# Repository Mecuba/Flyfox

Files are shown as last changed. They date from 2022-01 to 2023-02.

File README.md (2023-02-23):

# Flyfox | DIY Cablecam
Enlace al video de YouTube: https://www.youtube.com/watch?v=eEz6mBtRutU

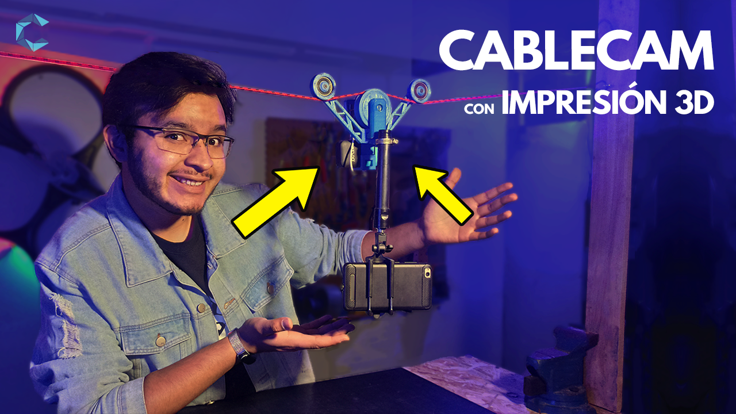
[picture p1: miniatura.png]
Flyfox Thumbnail (https://www.youtube.com/watch?v=eEz6mBtRutU)


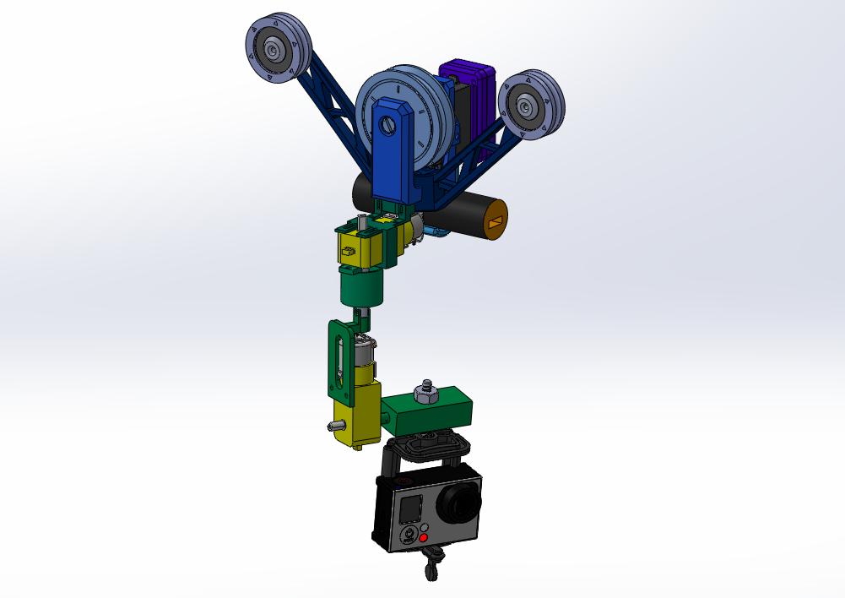
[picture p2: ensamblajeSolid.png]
Algoaca Thumbnail


Repo para guardar códigos y diseños mecánicos del Flyfox.

## Pendientes:
- Añadir algún día el estabilizador integrado como accesorio del Flyfox.
- Interfaz de control desde una app?

Si deseas más info sobre nuestro diseño de las piezas o hacer un diseño similar, escríbenos a: contacto.mecuba@gmail.com

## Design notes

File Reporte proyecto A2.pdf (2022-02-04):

### Benemérita Universidad Autónoma de Puebla Facultad de Ciencias de la Electrónica Avance II de proyecto Laboratorio Experimental de Sistemas Mecatrónicos

Nombre del proyecto:

### Desliza-inador

Fecha de entrega: 10 de noviembre de 2020 Fecha de envío: 10 de noviembre de 2020

Alumnos que la presentan:
Díaz Cisneros Sergio Fabrizzio | Jiménez Peña José Carlos
Flores Tecpoyotl Raymundo | Rojas López Daniel
González Montalvo Alejandro | Sánchez Saldaña Carlos Daniel

### I. Objetivo

Nuestro proyecto consiste en un dispositivo el cual es capaz de manipular los movimientos de una cámara, la cual estará sujetada al dispositivo a través de un sistema de sujeción, los movimientos se realizarán por medio de motores DC controlados por un potenciómetro. Nuestro dispositivo constará de dos movimientos principales, el primero será el desplazamiento de la cámara a través de una cuerda, el segundo consta de la rotación de la cámara para tener una vista de 360°. Como un adicional, se buscará lograr hacer una estabilización de la toma, aunque este punto no será tomado en cuenta para el mecanismo principal.

### II. Planos

Para empezar a plantear nuestro Desliza-inador, primero realizamos un prototipo en SolidWorks, mismo que será necesario en el análisis de este y la manipulación con Matlab y LabView.

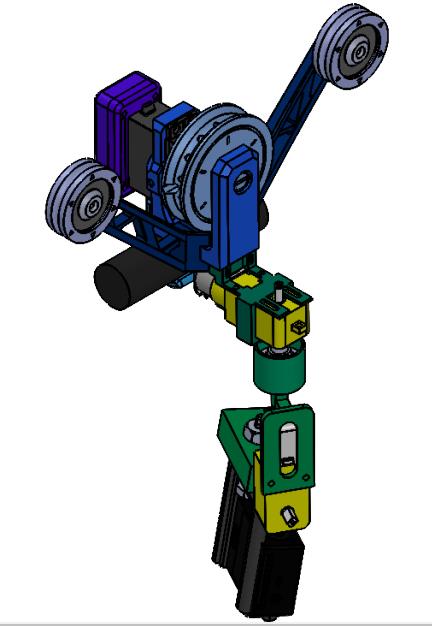
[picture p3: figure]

Figura 1. Desliza-inador en vista isométrica SolidWorks.

Planteamos 3 movimientos en nuestro sistema. El primero se trata de una traslación lineal sobre un eje, representado por ΔX en las figuras 2 y 3.
El segundo es un movimiento de giro ¨360¨ sobre un eje, el cuál resulta en el movimiento de giro de rotación sobre la cámara, siendo α en las figuras 2 y 3.
El tercero siendo un movimiento de giro acomodado en cadena bajo el movimiento 2, actuando como inclinación en la cámara, mostrado como γ en las figuras 2 y 3.

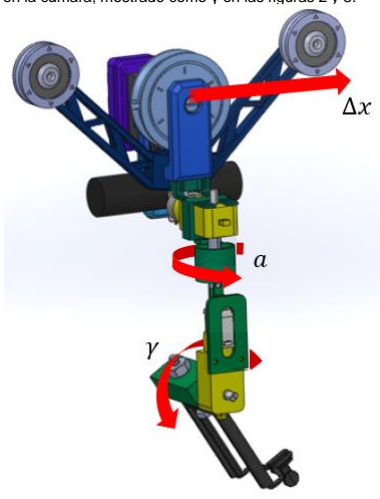
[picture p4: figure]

Figura 2. Desliza-inador en vista isométrica con ángulos de movimiento.

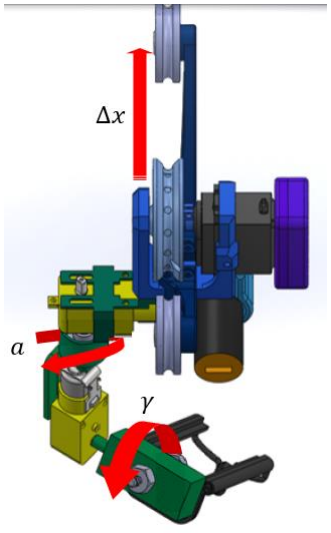
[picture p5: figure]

Figura 3. Desliza-inador con ángulos de giro en vista lateral. Podemos sintetizar los movimientos de nuestro sistema en el siguiente plano

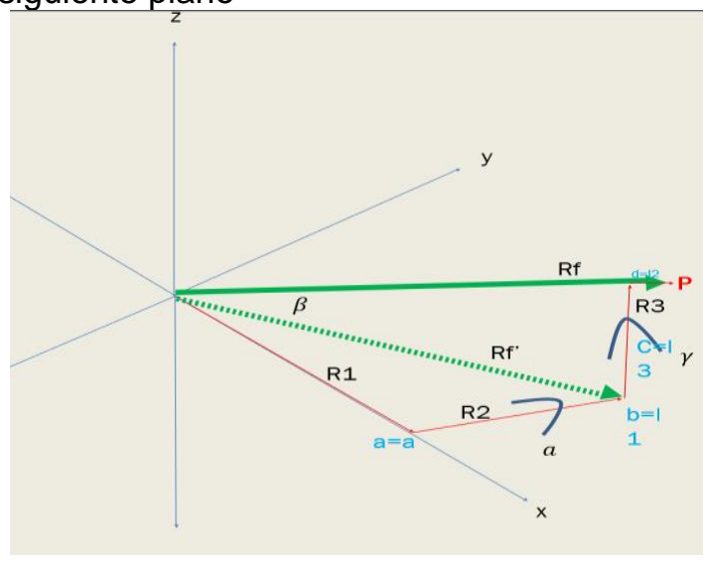
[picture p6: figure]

Figura 4. Plano 1

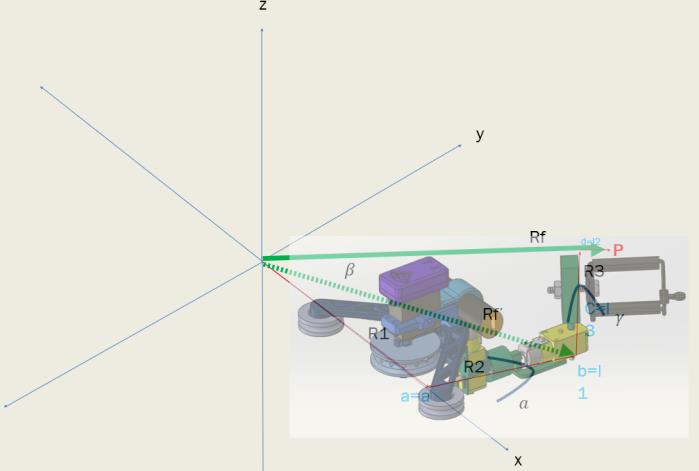
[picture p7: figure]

Figura 5. Plano 1 con representación directa.

Decidimos desplazar el Desliza-inador en el plano anterior reacomodando el sistema de referencia global para simplificar las ecuaciones y su adaptación a Matlab. El espacio (L1) que existe entre ΔX y α es una longitud invariable y resulta más fácil si ubicamos α en el eje X.
El deslizamiento principal ΔX sigue siendo sobre el eje X.
α ahora gira en paralelo al eje Y. L3 se puede mover en el plano XZ. Si el sistema está detenido como se muestra en la figura 6, L2 se puede mover en el plano XY, sin embargo, esto puede cambiar. Estos dos movimientos están relacionados estrechamente, el giro de α afecta directamente al punto P, el cual podría lograr movimientos circulares sobre el plano XY, esto cambiaria con el movimiento de γ rotando en el plano ZX.

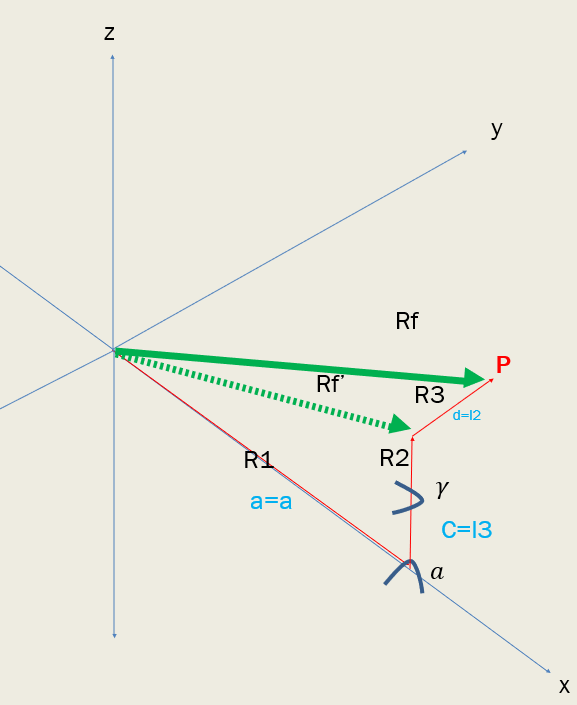
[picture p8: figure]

Figura 6. Plano 2

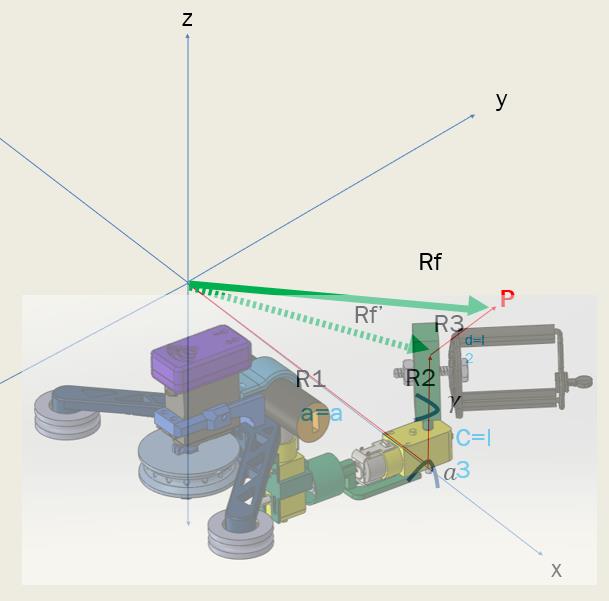
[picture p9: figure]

Figura 7. Plano 2 con representación directa.

Entonces para L2, al ser el segundo eslabón, no nos permite relacionar permanentemente solamente con un plano.
El movimiento que podemos imaginar se puede ver representado como la generación de anillos posibles dados por el giro de α. Formando una especie de dona que se puede deslizar en el eje X siendo este nuestro espacio muestral.

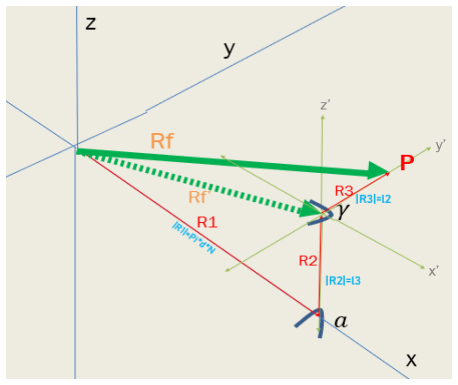
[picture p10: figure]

Figura 8. Plano 3

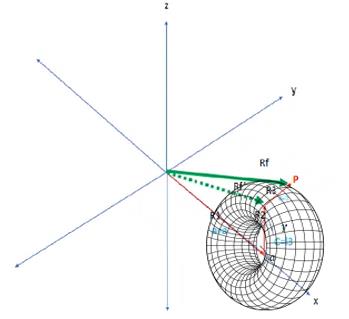
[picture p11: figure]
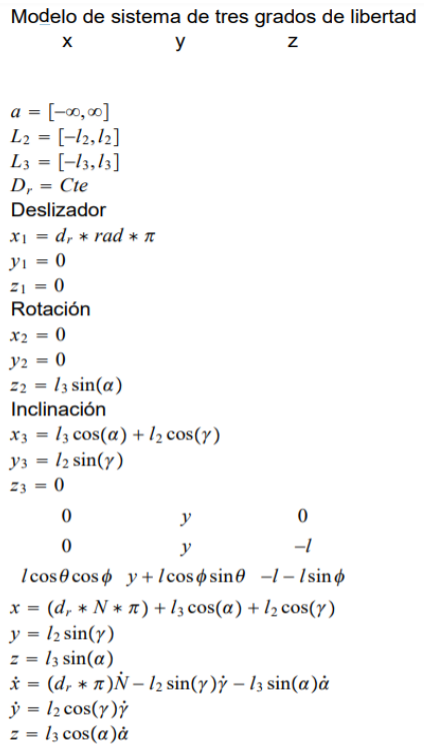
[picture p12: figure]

Figura 9. Plano 3 con representación de ¨dona¨

Si el movimiento de la dona se desliza en eje X, se generaría un prisma rectangular de posiciones posibles del punto P

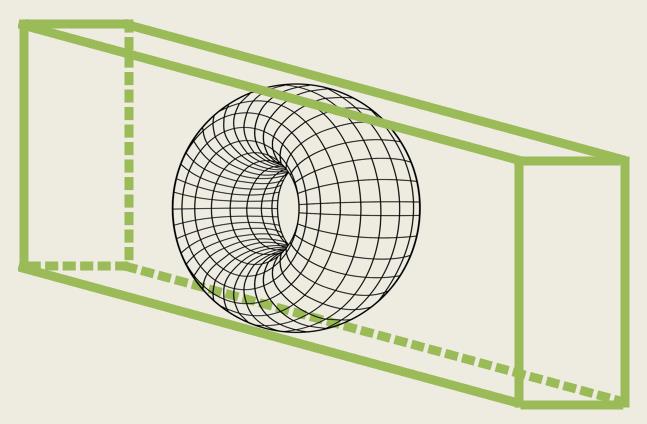
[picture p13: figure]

Figura 10. Espacio creado por el deslizamiento de la ¨dona¨

El deslizamiento podría ser considerado como infinito, generaría un rectángulo que se podría mover sobre x, dependiendo entonces de la cuerda sobre la cual este colocado el deslizador. Dominio de a: (-∞, ∞)î
El ancho de la caja seria 2 L2 comprendida de L2: (-L2, L2)ĵ
La altura L3 tendría dominio L3: (-L3, L3)k̂

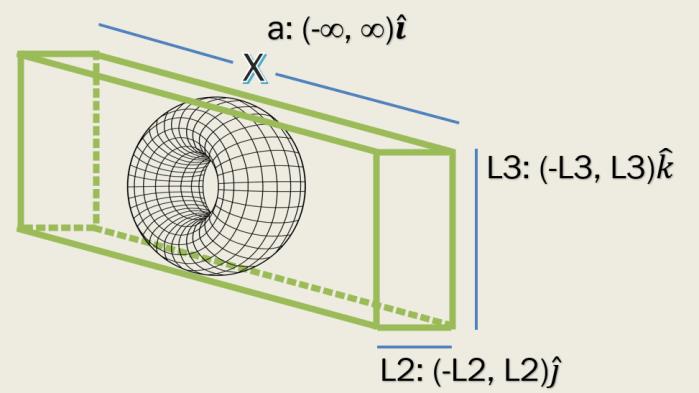
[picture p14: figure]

Figura 11. Parámetros del rectángulo generado.
III. | Matlab
Ya conociendo el sistema y | sus movimientos,
implementamos en Matlab para controlar el sistema. El código es el siguiente:

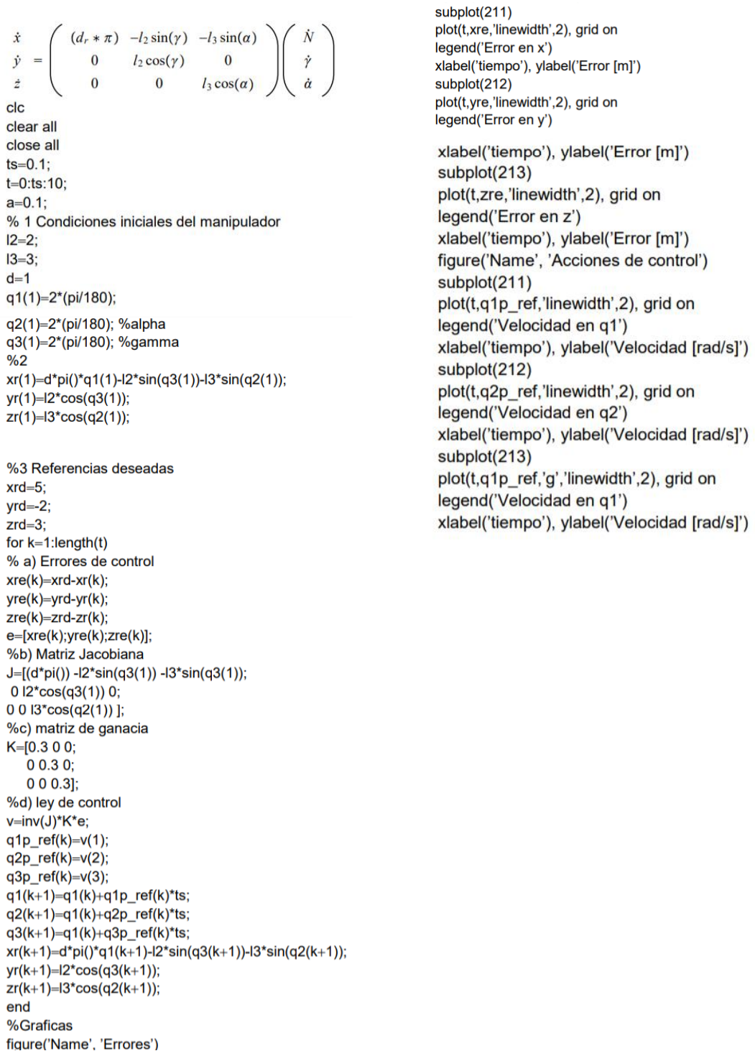
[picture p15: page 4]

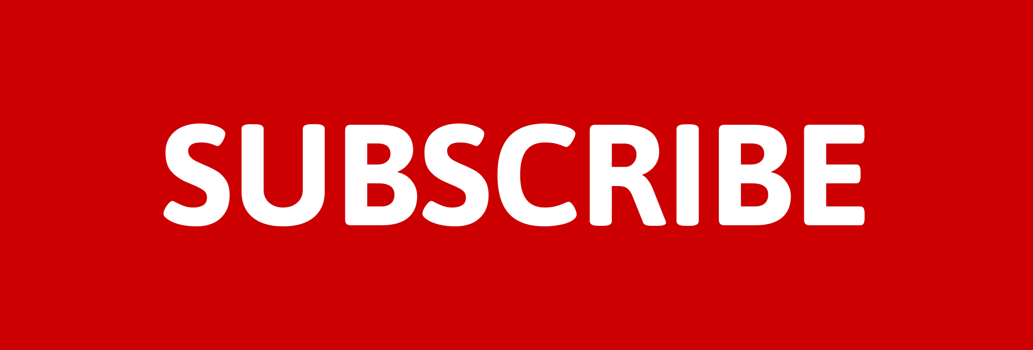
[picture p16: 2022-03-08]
CAD/STLs/youtube-subscribe-button/textures/subscribe.png

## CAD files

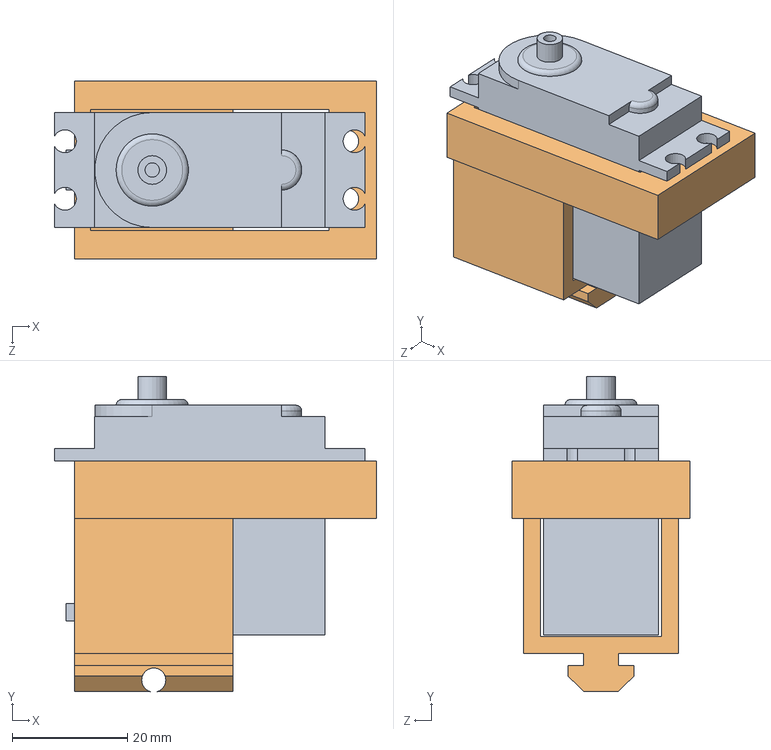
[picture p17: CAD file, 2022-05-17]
CAD/Flyfox - Ensamblaje Móvil con Servos/S20.000.v2 Pan.SLDASM
56.0 x 54.8 x 31.0 mm
servo strong junk 2.step
S20.002 Sujeta Servo Pan - PortaAccesorios

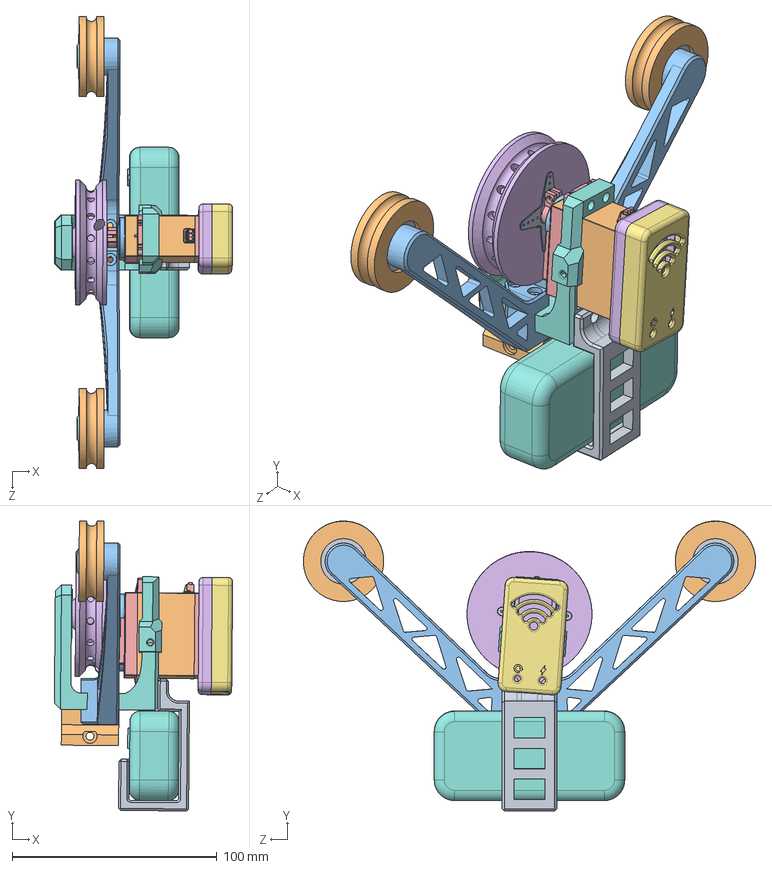
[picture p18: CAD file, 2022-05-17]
CAD/Flyfox - Ensamblaje Móvil con Servos/01 Flyfox Base/S10.000.v1.SLDASM
87.0 x 141.5 x 220.7 mm
Servo Futaba S3003.step
Servo Futaba S3003-0.step
Servo Futaba S3003-1.step
EMFutabaS3003_AxisFix
EMServoPolea
RodamientoServo^S10.000.v1
EMBastidorCentral x 2
EMRodamiento28x11.5x8 x 2
EMRodamientoSuit x 2
EMRightArm x 2
EMRodamientoRin x 2
MG995.step
Bottom.step
Top.step
EMPowerBank-Cuadrado
EMPortaPowerBank_Cuadrado
EMSlider-PortaAccesorios

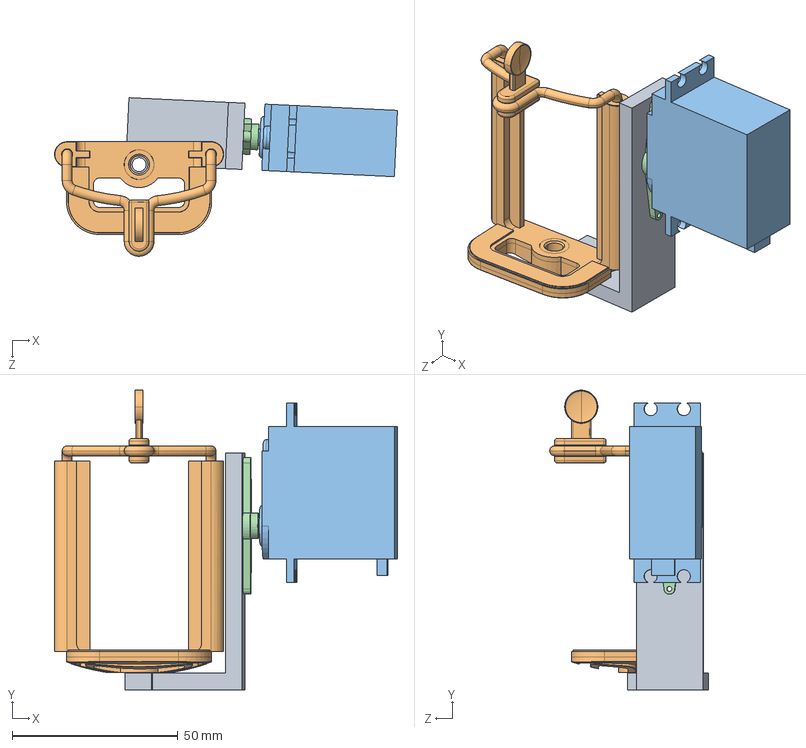
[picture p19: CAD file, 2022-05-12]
CAD/Flyfox - Ensamblaje Móvil con Servos/03 Tilt/S30.000.v1 Tilt.SLDASM
103.3 x 90.3 x 47.8 mm
S30.001 sujeta portatelefono
phone_holder
servo strong junk 2.step
servo strong junk 1.step

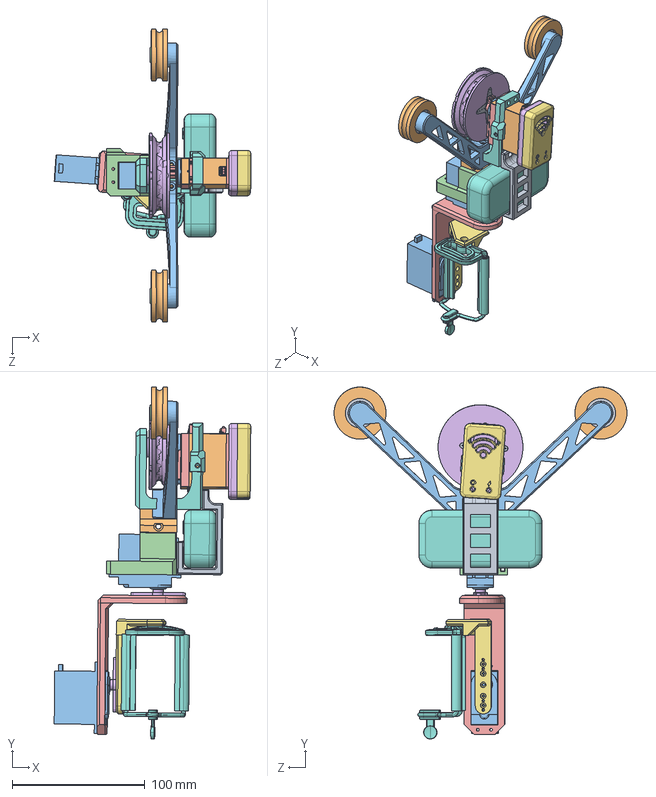
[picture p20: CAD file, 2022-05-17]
CAD/Flyfox - Ensamblaje Móvil con Servos/Ensamblaje_Movil_Flyfox_con_Torreta.SLDASM
148.2 x 265.2 x 220.7 mm
Servo Futaba S3003.step
Servo Futaba S3003-0.step
Servo Futaba S3003-1.step
EMFutabaS3003_AxisFix
RodamientoServo^S10.000.v1
EMBastidorCentral x 2
EMRodamiento28x11.5x8 x 2
EMRodamientoSuit x 2
EMRightArm x 2
EMRodamientoRin x 2
MG995.step
Bottom.step
Top.step
EMPowerBank-Cuadrado
EMPortaPowerBank_Cuadrado
EMSlider-PortaAccesorios
servo strong junk 2.step x 2
S20.002 Sujeta Servo Pan - PortaAccesorios
S20.001 Cople Pan-Tilt
servo mg995 horn 2 sides.step x 2
S30.001 sujeta portatelefono
phone_holder
EMServoPolea

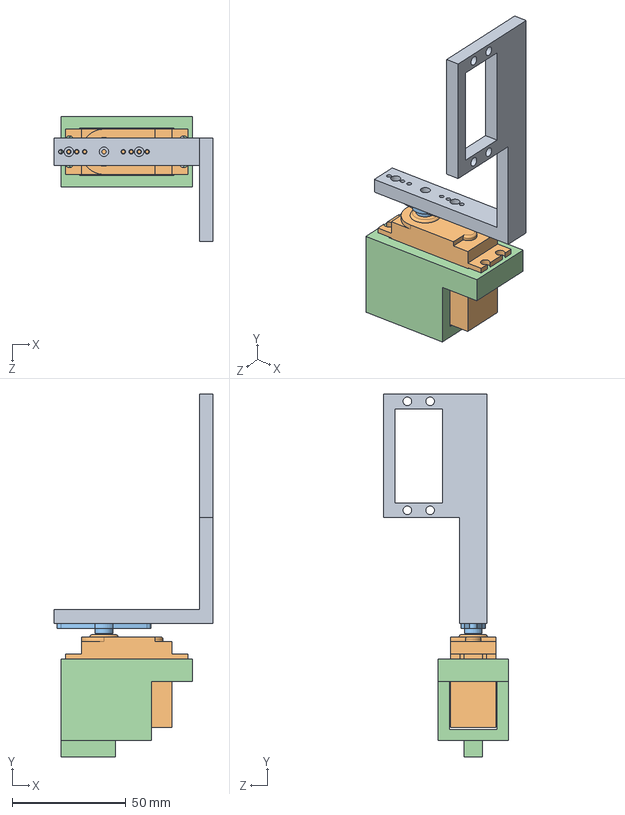
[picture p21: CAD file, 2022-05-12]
CAD/Flyfox - Ensamblaje Móvil con Servos/02 Pan/Ensamblaje2.SLDASM
70.0 x 159.9 x 55.0 mm
S20.001 Cople Pan-Tilt
servo strong junk 2.step
servo strong junk 1.step
S20.002 Sujeta Servo Pan - PortaAccesorios

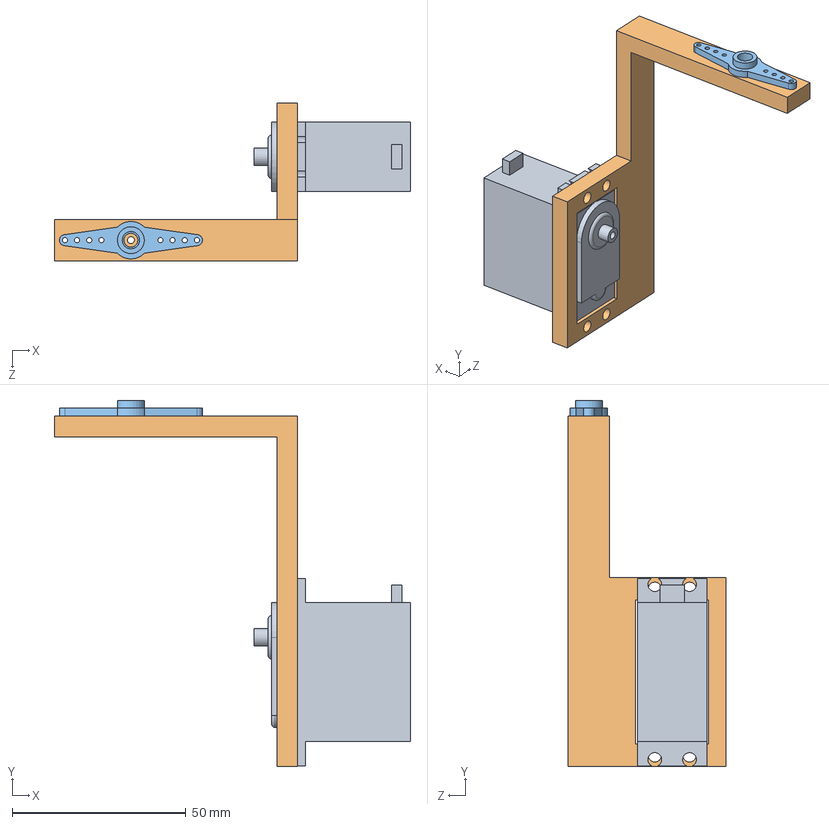
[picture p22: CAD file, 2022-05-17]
CAD/Flyfox - Ensamblaje Móvil con Servos/S30.000.v2 Tilt.SLDASM
102.5 x 105.5 x 45.5 mm
servo strong junk 2.step
S20.001 Cople Pan-Tilt
servo mg995 horn 2 sides.step

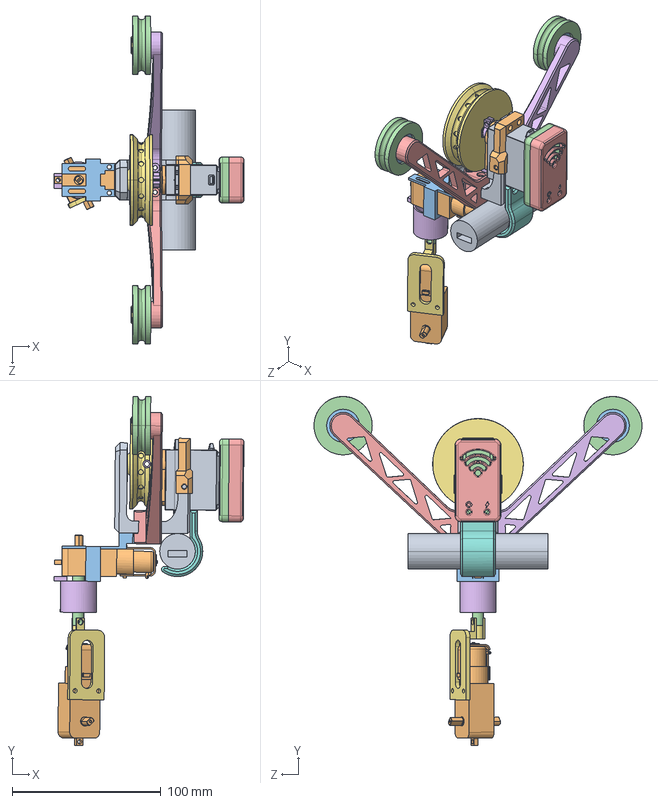
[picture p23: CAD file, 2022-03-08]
CAD/Servo Cable Cam (CUBA).SLDASM
127.8 x 234.9 x 220.7 mm
Servo Futaba S3003.step.STEP
Servo Futaba S3003-0.step.STEP
Servo Futaba S3003-1.step.STEP
Bottom.step.STEP
Top.step.STEP
FutabaS3003_AxisFix.STEP
ServoPolea.STEP
Pieza1^Servo Cable Cam.STEP
BastidorCentral_TopCut.STEP
Rodamiento28x11.5x8.STEP x 2
RodamientoSuit.STEP x 2
RightArm.STEP
RightArm_LeftMirror.STEP
RodamientoRin.STEP x 2
PortaPowerBank_Duracell.STEP
PowerBank-Dummy.STEP
Hobby_GearMotor x 2
Pieza2
Union Motor 1 y 2^Servo Cable Cam (Motor reductor)
Pieza7^Servo Cable Cam (Motor reductor)
Pieza8^Servo Cable Cam (Motor reductor)
Soporte Motor 2

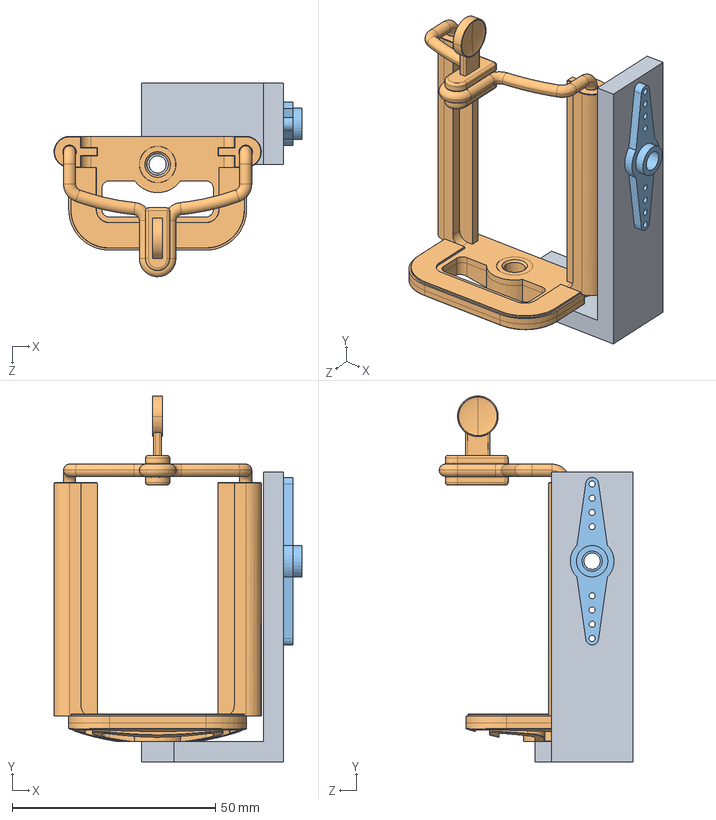
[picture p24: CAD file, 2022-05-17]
CAD/Flyfox - Ensamblaje Móvil con Servos/S40.000.v2 CAMERA END.SLDASM
61.0 x 90.0 x 47.6 mm
S30.001 sujeta portatelefono
phone_holder
servo mg995 horn 2 sides.step

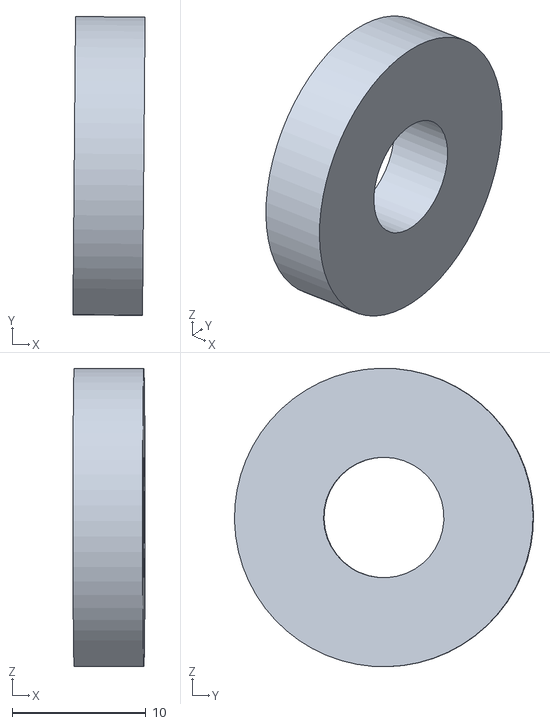
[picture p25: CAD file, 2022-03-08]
CAD/STLs/flyfox para gravity sketch/flyfox - RodamientoServo^Desliza-inador (Ensamblaje Completo).STL
5.39 x 22.3 x 22.3

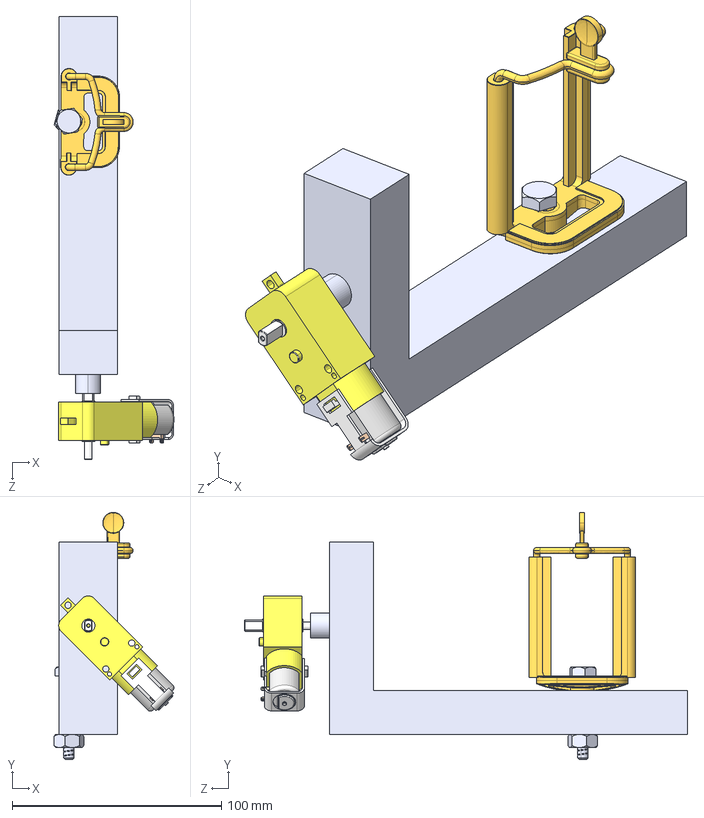
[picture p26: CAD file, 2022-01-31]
CAD/Ensamblaje Fabrizz.STEP
57.3 x 118.1 x 211.6 mm
Hobby_GearMotor
phone_holder
Tornillo
Tuerca
Sujeta Pinza

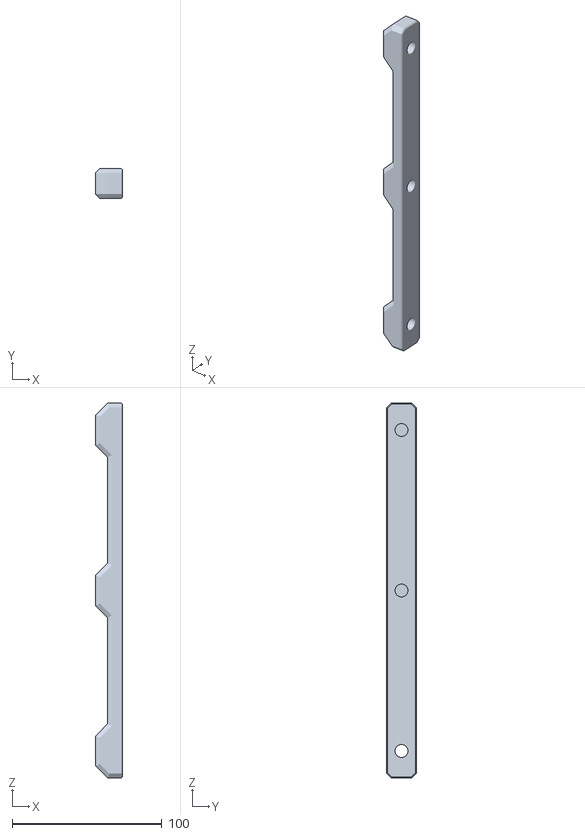
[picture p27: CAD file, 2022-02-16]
CAD/Accesorios/Carrete-Brazo para manviela.STL
18.0 x 20.0 x 250.0

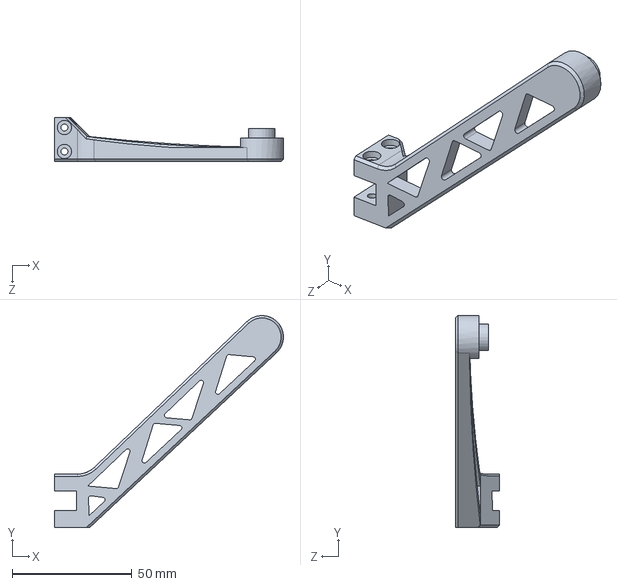
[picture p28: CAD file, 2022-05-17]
CAD/Flyfox - Ensamblaje Móvil con Servos/01 Flyfox Base/EMRightArm.SLDPRT
95.6 x 88.5 x 18.5 mm

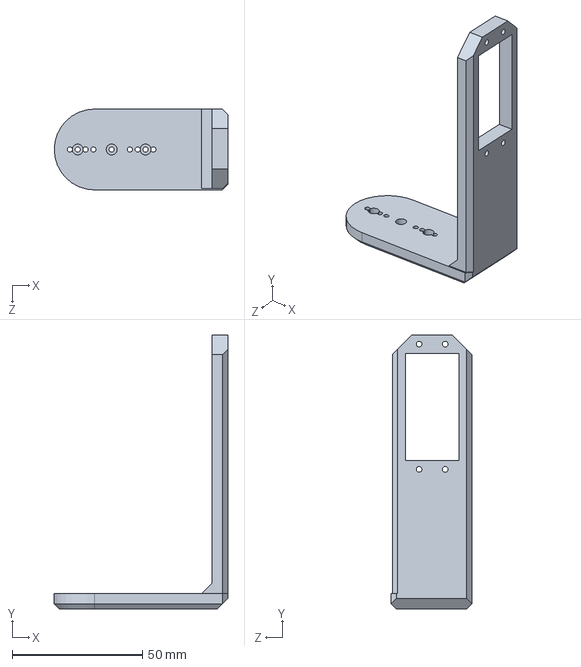
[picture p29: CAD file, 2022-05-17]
CAD/Flyfox - Ensamblaje Móvil con Servos/02 Pan/S20.001 Cople Pan-Tilt.SLDPRT
66.5 x 105.0 x 31.0 mm

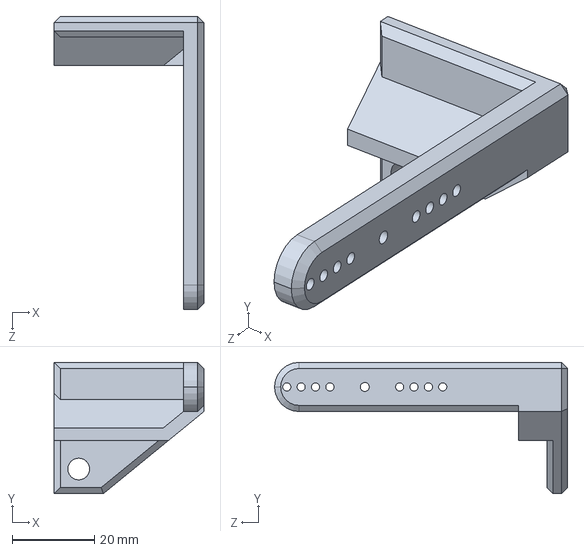
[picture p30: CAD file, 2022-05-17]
CAD/Flyfox - Ensamblaje Móvil con Servos/03 Tilt/S30.001 sujeta portatelefono.SLDPRT
36.5 x 32.0 x 71.4 mm

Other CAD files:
CAD/Flyfox - Ensamblaje Móvil con Servos/STEP Files/NodeMCU_Case_V2.step.STEP.sldasm
CAD/Servo Futaba S3003 v6.step.STEP.sldasm
CAD/Servo Cable Cam.STEP.sldasm
CAD/Flyfox - Ensamblaje Móvil con Servos/STEP Files/MG995_Gear2.STEP
CAD/Accesorios/Carrete-Brazo con manviela.SLDPRT
CAD/Accesorios/Carrete-Brazo para eje.STL
CAD/Accesorios/Finales de línea.SLDPRT
CAD/Accesorios/Finales de línea.STL
CAD/BastidorCentral.SLDPRT
CAD/BastidorCentral_RestCut.STEP.sldprt
CAD/BastidorCentral_TopCut.STEP.sldprt
CAD/Bottom.step.STEP.sldprt
CAD/Desliza-inador (Flyfox).SLDDRW
CAD/Flyfox - Ensamblaje Móvil con Servos/01 Flyfox Base/EMBastidorCentral.SLDPRT
CAD/Flyfox - Ensamblaje Móvil con Servos/01 Flyfox Base/EMFutabaS3003_AxisFix.SLDPRT
CAD/Flyfox - Ensamblaje Móvil con Servos/01 Flyfox Base/EMPortaPowerBank_Cuadrado.SLDPRT
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

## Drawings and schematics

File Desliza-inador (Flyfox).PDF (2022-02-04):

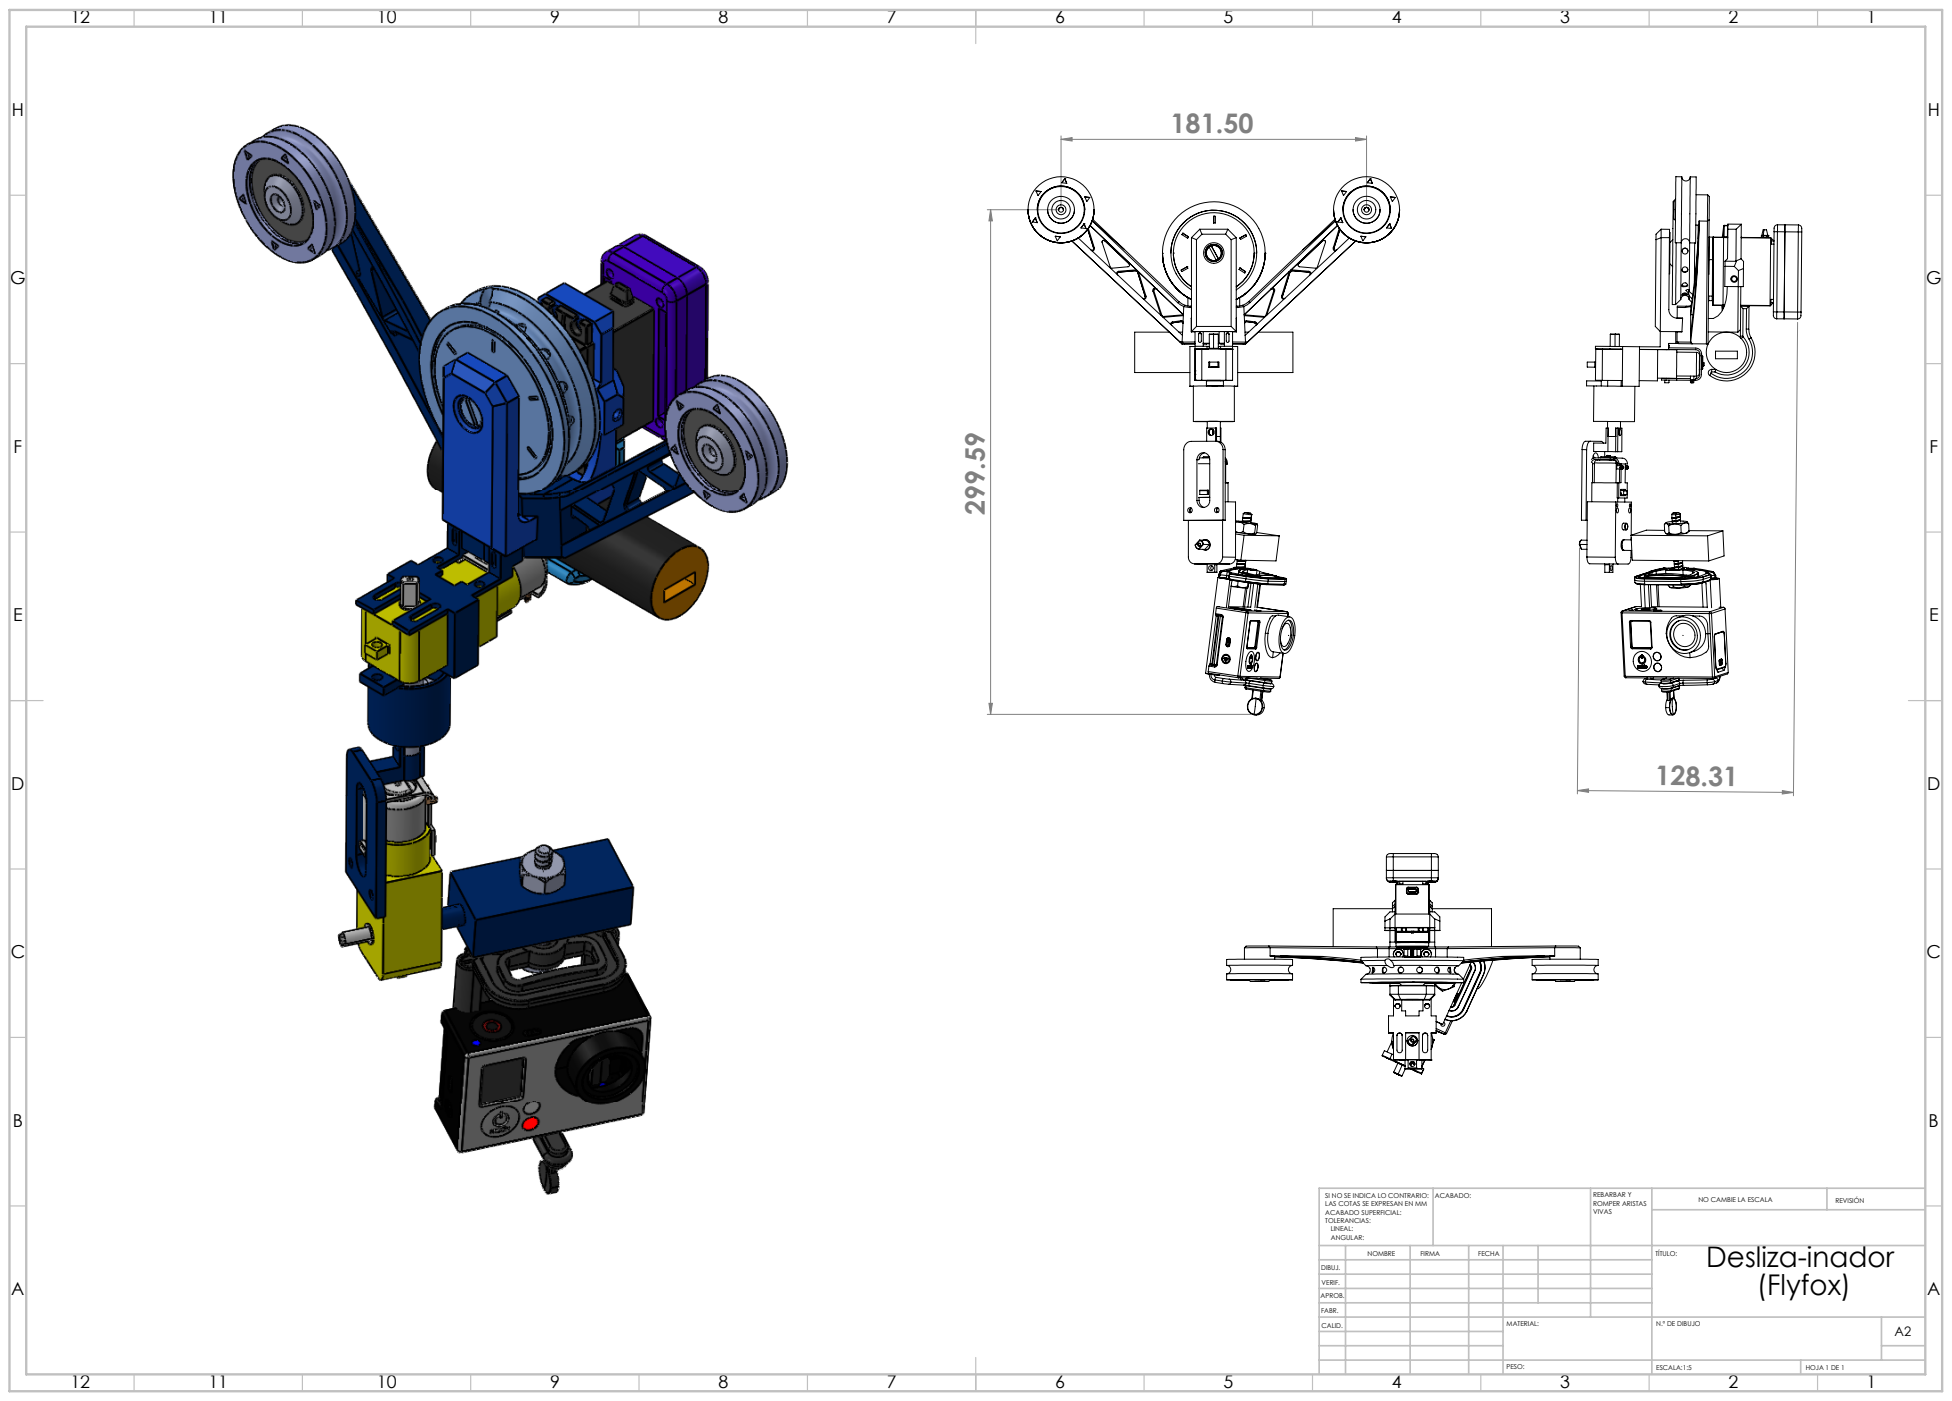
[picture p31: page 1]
ESCALA:1:5; HOJA 1 DE 1

SI NO SE INDICA LO CONTRARIO: LAS COTAS SE EXPRESAN EN MM ACABADO SUPERFICIAL: TOLERANCIAS: LINEAL: ANGULAR: | ACABADO: | REBARBAR Y ROMPER ARISTAS VIVAS | NO CAMBIE LA ESCALA | REVISIÓN

NOMBRE | FIRMA | FECHA | | | | Desliza-inador TÍTULO: (Flyfox)

DIBUJ.
VERIF.
APROB.
FABR.
CALID. | | | | MATERIAL: | N.º DE DIBUJO | A2

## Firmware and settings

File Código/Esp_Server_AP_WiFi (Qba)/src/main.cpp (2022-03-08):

#include <Arduino.h>
#include <ESP8266WebServer.h>
#include <ESP8266WiFi.h>
#include <WiFiClient.h>
#include <WebSocketsServer.h>
#include <Servo.h>
#include <string>

///Pagina html index.html/// 
#include <index.h>
#include <submit.h>
#include <error.h> //Aun no esta xd 

//Led de prueba: 
#define D4 2

//Declaramos el servo
Servo FlyServo; //Nombre del servo
#define servoPin D3 // El servo en el pin D3

//Parametros del bot
bool play = false;  
int range = 0; //Valor del slider: de 0 a 100* )99)
int sliderNum = 162;

//Parametros de red: 
String ip ;
IPAddress ipStatic(192,168,100,82);
IPAddress ipGateway(192,168,0,1);
IPAddress subnet(255,255,255,0); 
const char* ssid = "Flyfox-AP"; //Nombre del punto de acceso.
char* password;
char* nombre; 

//Contadores: 
int i = 0; 

//Iniciamos el sevidor en el puerto 80: 
ESP8266WebServer server(80);
WebSocketsServer webSockets = WebSocketsServer(81); 

/// Funciones: ////
bool toggle_button(String payload){
  //Cambia el valor del estado: 
  if (payload == "play")
        {
          return true;
        }else{
          return false;
        }
}
bool connected_to_wifi(char* name, char* pass){
  //Devuelve true si se pudo conectar: 

  Serial.printf("nombre: %s",name); 
  WiFi.config(ipStatic, ipGateway, subnet);
  WiFi.begin(name, pass); 
  Serial.print("\n\r ....");
  int time_finish = 0; 
  unsigned long int actual_time = millis();
  unsigned long int prev_time = millis();
  while ((WiFi.status() != WL_CONNECTED) && (time_finish != 1)){ 
    actual_time = millis();
    delay(200);
    Serial.println("No connected");
    if(actual_time - prev_time > 15000){
      prev_time = actual_time;
      time_finish = 1;
      Serial.println("Acabo el tiempo"); 
      return false;
    } 
  }return true;
}
void AP_mode(){
  //Crea un AP: 
  WiFi.softAP(ssid); 
  IPAddress miIP = WiFi.softAPIP(); //IP por default: 192.168.4.1  
  ip = miIP.toString();
  Serial.println("IP del APoint"); 
  Serial.println(miIP);
  Serial.println(WiFi.localIP()); 
}

//Manejo de peticiones http:  
void control_root(){
  //Interfaz de control:
   server.send(200,"text/html", html);
}
void handle_root(){
  String ip_AP = "192.168.4.1"; 
  if(ip == ip_AP){
    server.send(200, "text/html", submit_html);  
    Serial.println("Submit");
  }else{ 
    server.send(200,"text/html", html);
    Serial.println("Control root"); 
  }
}
void error_root(){
  server.send(200, "text/html", error);
}

//Manejo de las peticiones de websockets: 
void webSocketEvent(uint8_t num, WStype_t type, uint8_t *payload, size_t welength)
{
  String payloadString = (char *)payload;
  
  if(type == WStype_TEXT) 
  {
  // Que tipo de conexion es: 
  switch(type) {

    // Client has disconnected
    case WStype_DISCONNECTED:
      Serial.printf("[%u] Disconnected!\n", num);
      break;

    // New client has connected
    case WStype_CONNECTED:
      {
        IPAddress ip = webSockets.remoteIP(num);
        Serial.printf("[%u] Connection from ", num);
        Serial.println(ip.toString());
      }
      break;

    // Echo text message back to client
    case WStype_TEXT:
    { 
      Serial.printf("[%u] Text: %s\n", num, payload);
      char str1[30]; //Usado para dividir cadena de entrada del websocket. 
      for (int i = 0; i < payloadString.length(); i++)
      {
        str1[i] = {payloadString[i]};
      }  
      char* payloadString_first_position = strtok(str1, ",");
      char* payloadString_second_position = strtok(NULL, "");

      String payloadStringfirst = (char *)payloadString_first_position; 
      String payloadStringsecond = (char *)payloadString_second_position;       
      Serial.printf("payloadString_first_position: %s \n", payloadString_first_position); 
      
      //Verifica si son valores del slider: //ACÁ EDITAR PARA SERVO----------------------------------
      if(payloadStringfirst == "range"){
        range = payloadStringsecond.toInt();
        Serial.printf("Range: %i \n", range); 
        sliderNum = map(range, 0, 99, 144, 180);
        Serial.printf("sliderNum: %i \n", sliderNum); 

      //Si es play o stop: 
      }else if (payloadString == "play" || payloadString == "stop"){
        play = toggle_button(payloadString);
        Serial.println(play); 
        if(play)
        {
          
          //FlyServo.attach(servoPin);
          //delay(1000);
          FlyServo.write(sliderNum); //Rotate the servo
          Serial.println(sliderNum);
        }
        else
        {
          FlyServo.write(162); //Rotate the servo
          Serial.println(162);
          //FlyServo.detach();
        }

      //Si son credenciales de internet: 
      }else{
        char str[30]; //Usado para dividir cadena de entrada del websocket. 
        for (int i = 0; i < payloadString.length(); i++)
        {
          str[i] = {payloadString[i]};
        }  

        nombre = strtok(str, ","); 
        password = strtok(NULL, ""); 

        //Intenta conectarse a la red: 
        Serial.printf("nombre: %s, contraseña: %s",nombre, password); 
        WiFi.config(ipStatic, ipGateway, subnet);
        WiFi.begin(nombre, password); 
        Serial.print("\n\r ....");
        int time_finish = 0; 
        unsigned long int actual_time = millis();
        unsigned long int prev_time = millis();
        while ((WiFi.status() != WL_CONNECTED) && (time_finish != 1)){ 
        actual_time = millis();
        delay(200);
        Serial.println("No connected");
        if(actual_time - prev_time > 13000){
          prev_time = actual_time;
          time_finish = 1;
          Serial.println("Acabo el tiempo"); 
          } 
        }
        //No se pudo conectar: 
        if(WiFi.status() != WL_CONNECTED){
          Serial.println("No se pudo conectar"); 
          WiFi.disconnect(); 
        }
        //Se conecto: 
        else{
          Serial.println("Wifi conectada en la ip 192.168.100.82");  
          ip = "192.168.100.82"; 
          digitalWrite(D4,HIGH); 
        }
      }
    }
      break;

    // For everything else: do nothing
    case WStype_BIN:
    case WStype_ERROR:
    case WStype_FRAGMENT_TEXT_START:
    case WStype_FRAGMENT_BIN_START:
    case WStype_FRAGMENT:
    case WStype_FRAGMENT_FIN:
    default:
      break;
  }
  }
}


void setup() { //----------------------------------------------------------------------SETUP-------------------------------------------
  Serial.begin(9600);
  delay(500);
  Serial.println("Encendiendo Flyfox...");
  FlyServo.attach(servoPin);
  delay(100);
  FlyServo.write(162);
  int pos;

  for (pos = 0; pos <= 180; pos += 1) { // goes from 0 degrees to 180 degrees
    // in steps of 1 degree
    FlyServo.write(pos);              // tell servo to go to position in variable 'pos'
    Serial.println(pos);
    delay(200);                       // waits 15 ms for the servo to reach the position
  }
  for (pos = 180; pos >= 0; pos -= 1) { // goes from 180 degrees to 0 degrees
    FlyServo.write(pos);              // tell servo to go to position in variable 'pos'
    Serial.println(pos);
    delay(200);                       // waits 15 ms for the servo to reach the position
  }

  WiFiMode(WIFI_AP_STA);
  //Intenta conectarse a una red pasada (AUN NO ESTA)
  if(nombre != NULL){
    if(connected_to_wifi(nombre, password) != true){
      Serial.println("No se pudo conectar inicio");
    }
  }
  
  AP_mode();
  /////// Manejo de las req: /////
  Serial.println("Hadle_server");
  server.on("/", handle_root); 
  server.on("/index", control_root); 
  server.on("/error", error_root); 

  //Leds indicadores: 
  pinMode(D4, OUTPUT);

  /// Inicio de los servidores ////
  webSockets.onEvent(webSocketEvent); 
  server.begin();
  webSockets.begin();
  Serial.println("Server start"); 
  
}

void loop() {
  server.handleClient();
  webSockets.loop();  
}

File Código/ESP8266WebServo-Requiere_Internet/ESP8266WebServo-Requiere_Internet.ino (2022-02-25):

#include <ESP8266WiFi.h>
#include <Servo.h>

Servo FlyServo;  // create servo object to control a servo
// twelve servo objects can be created on most boards

// GPIO the servo is attached to
#define servoPin  D3 // El servo en el terminal D3

// Replace with your network credentials
const char* ssid     = "Habia una vez";
const char* password = "-truz, jaja";

// Set AP credentials
#define AP_SSID "Flyfox"
#define AP_PASS "picaporte"

// Set web server port number to 80
WiFiServer server(80);

// Variable to store the HTTP request
String header;

// Decode HTTP GET value
String valueString = String(5); 
int pos1 = 0;
int pos2 = 0;
int sliderNum = 105;
bool flag = false;

void setup() {
  Serial.begin(115200);
  pinMode(LED_BUILTIN, OUTPUT);

  // Connect to Wi-Fi network with SSID and password
  Serial.print("Connecting to ");
  Serial.println(ssid);
  WiFi.begin(ssid, password);
  while (WiFi.status() != WL_CONNECTED) {
    delay(500);
    Serial.print(".");
  }
  // Print local IP address and start web server
  Serial.println("");
  Serial.println("WiFi connected.");
  Serial.println("IP address: ");
  Serial.println(WiFi.localIP());

  WiFi.softAP(AP_SSID, AP_PASS);
  Serial.print(AP_SSID);
  Serial.print(" : ");
  Serial.print(WiFi.softAPIP());

  delay(1000);
  server.begin();
}

void loop(){
  WiFiClient client = server.available();   // Listen for incoming clients
  
  if (client) {                             // If a new client connects,
    digitalWrite(LED_BUILTIN, HIGH); 
    Serial.println("New Client.");          // print a message out in the serial port
    String currentLine = "";                // make a String to hold incoming data from the client
    while (client.connected()) {            // loop while the client's connected
      if (client.available()) {             // if there's bytes to read from the client,
        char c = client.read();             // read a byte, then
        Serial.write(c);                    // print it out the serial monitor
        header += c;
        if (c == '\n') {                    // if the byte is a newline character
          // if the current line is blank, you got two newline characters in a row.
          // that's the end of the client HTTP request, so send a response:
          if (currentLine.length() == 0) {
            // HTTP headers always start with a response code (e.g. HTTP/1.1 200 OK)
            // and a content-type so the client knows what's coming, then a blank line:
            client.println("HTTP/1.1 200 OK");
            client.println("Content-type:text/html");
            client.println("Connection: close");
            client.println();

            // Display the HTML web page
            client.println("<!DOCTYPE html><html>");
            client.println("<head><meta name=\"viewport\" content=\"width=device-width, initial-scale=1\">");
            client.println("<link rel=\"icon\" href=\"data:,\">");
            // CSS to style the on/off buttons 
            // Feel free to change the background-color and font-size attributes to fit your preferences
            client.println("<style>body { text-align: center; font-family: \"Trebuchet MS\", Arial; margin-left:auto; margin-right:auto;}");
            client.println(".slider { width: 300px; }</style>");
            client.println("<script src=\"https://ajax.googleapis.com/ajax/libs/jquery/3.3.1/jquery.min.js\"></script>");
                     
            // Web Page
            client.println("</head><body><h1>ESP8266 Servo Cable Cam</h1>");
            client.println("<p>Position: <span id=\"servoPos\"></span></p>");          
            client.println("<input type=\"range\" min=\"50\" max=\"150\" value=\"105\" class=\"slider\" id=\"servoSlider\" onchange=\"servo(this.value)\" value=\""+valueString+"\"/>");
            
            client.println("<script>var slider = document.getElementById(\"servoSlider\");");
            client.println("var servoP = document.getElementById(\"servoPos\"); servoP.innerHTML = slider.value;");
            client.println("slider.oninput = function() { slider.value = this.value; servoP.innerHTML = this.value; }");
            client.println("$.ajaxSetup({timeout:1000}); function servo(pos) { ");
            client.println("$.get(\"/?value=\" + pos + \"&\"); {Connection: close};}</script>");
           
            client.println("</body></html>");     
            
            //GET /?value=180& HTTP/1.1
            
            if(header.indexOf("GET /?value=")>=0) {
              pos1 = header.indexOf('=');
              pos2 = header.indexOf('&');
              valueString = header.substring(pos1+1, pos2);

              sliderNum = valueString.toInt();
              
              if(sliderNum < 110 && sliderNum > 100) //Zona muerta para dejar quieto el servo
              {
                FlyServo.detach();
                flag = false;
              }
              else 
              {
                if(flag == false) //Para que sólo se Attach-ee una vez saliendo de la zona muerta
                {
                  FlyServo.attach(servoPin);
                  flag = true;
                }
                FlyServo.write(sliderNum); //Rotate the servo
                Serial.println(valueString); 
              }
              
            }
                     
            // The HTTP response ends with another blank line
            client.println();
            // Break out of the while loop
            break;
          } else { // if you got a newline, then clear currentLine
            currentLine = "";
          }
        } else if (c != '\r') {  // if you got anything else but a carriage return character,
          currentLine += c;      // add it to the end of the currentLine
        }
      }
    } //Aquí ya no hay cliente
    // Clear the header variable
    header = "";
    // Close the connection
    client.stop();
    Serial.println("Client disconnected.");
    Serial.println("");
    digitalWrite(LED_BUILTIN, LOW); 
  }
}

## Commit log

2022-01-31 Subiendo archivos iniciales
    [BastidorCentral.SLDPRT, BastidorCentral_Bottom.STL, BastidorCentral_RestCut.STEP.sldprt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]
2022-02-02 Finales de línea
    Accesorio que funciona como freno rígido para el deslizador en ambos extremos de la línea de carrera
    [Finales de línea.SLDPRT]
2022-02-02 Correcciones para impresión
    La pieza además tiene dos versiones: la default para impresión casi libre de voladizos y la optimizada para ahorrar material pero con riesgo de voladizos
    [Finales de línea.SLDPRT]
2022-02-03 Finales de línea listos para impresión
    [Finales de línea.STL]
2022-02-03 Correcciones de curvatura
    [Finales de línea.STL]
2022-02-04 planos Flyfox
    [Desliza-inador (Flyfox).SLDDRW, Pieza2.sldprt, Pieza8^Servo Cable Cam (Motor reductor).sldprt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]
2022-02-07 Cambio de color
2022-02-11 Recivo de datos desde el cliente
2022-02-16 Brazos del carrete
    [Carrete-Brazo con manviela.STL, Carrete-Brazo normal.STL]
2022-02-16 Uniones para el carrete de la cuerda
    Dos versiones de una misma pieza en el mismo archivo, una con el agujero en el centro para el eje y otra con el agujero en un extremo para la manivela
    [Carrete-Brazo con manviela.SLDPRT]
2022-02-16 Uniones para el carrete de la cuerda
    Dos versiones de una misma pieza, una con el agujero en el centro para el eje y otra con el agujero en un extremo para la manivela
    [Carrete-Brazo para eje.STL, Carrete-Brazo para manviela.STL]
2022-02-17 Cambio de nombre
2022-02-22 Cambio de nombre en README
2022-02-25 cuando se conecta a la red aparece la pestaña de control
2022-02-25 Cuando se conecta a la red el led se apaga
2022-02-25 Ver_1.3 llegada de valores completed
2022-02-25 Llegada de los valores
2022-02-25 Pruebas antes de salir
2022-03-08 Clonar codigo para servo raro que sólo corre en arduino
    [MG995.STEP, PortaPowerBank_Cuadrado.SLDPRT, PortaPowerBank_Duracell.SLDPRT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]
2022-05-12 ensamblaje movil para Ardul
    [02 Flyfox - Servo PortaAccesorios.STEP, EMBastidorCentral.SLDPRT, EMFutabaS3003_AxisFix.SLDPRT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]
2022-05-12 Rotar polea del servo
    [02 Flyfox - Servo PortaAccesorios.STEP, EMBastidorCentral.SLDPRT, EMFutabaS3003_AxisFix.SLDPRT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]
2022-05-17 Pruebas con torreta noche previa a entrega Ardul
    [02 Flyfox - Servo PortaAccesorios.STEP, EMBastidorCentral.SLDPRT, EMFutabaS3003_AxisFix.SLDPRT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]
